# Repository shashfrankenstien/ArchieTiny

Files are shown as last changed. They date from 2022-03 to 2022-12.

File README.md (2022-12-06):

# Archie Tiny OS (ATtiny85)

- https://hackaday.io/project/185844-archie-tiny

<p align="center">
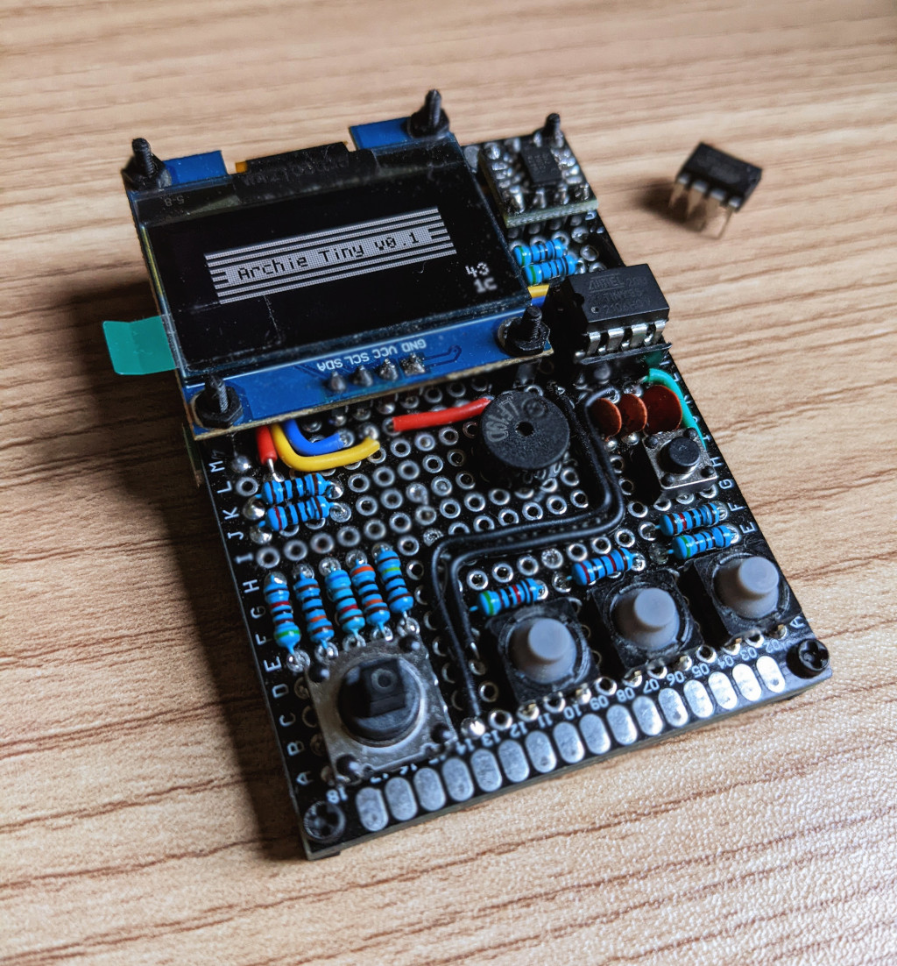
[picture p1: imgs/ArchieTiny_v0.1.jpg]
  
</p>

- https://www.youtube.com/playlist?list=PLuCmHWky5GN4iyRNNchJ4GMcVCSOgdOvc
- http://www.avr-asm-tutorial.net/
- https://blog.oddbit.com/post/2019-01-22-debugging-attiny-code-pt-1/
- http://www.rjhcoding.com/avr-asm-macros.php
- https://www.youtube.com/watch?v=tFSTG7XEboI&list=PLuCmHWky5GN4iyRNNchJ4GMcVCSOgdOvc&index=5
- https://ftp.gnu.org/pub/old-gnu/Manuals/gas-2.9.1/html_chapter/as_7.html

### Portability (CR2477 at 1000 mAh??)
- https://www.batteriesandbutter.com/coin_batttery_chart.html
- http://howardtechnical.com/voltage-divider-calculator/

## Debugging
- https://github.com/vince-br-549/ESP8266-as-ISP
- https://randomnerdtutorials.com/arduino-poor-mans-oscilloscope/
- https://sites.google.com/site/wayneholder/debugwire2
- https://sites.google.com/site/wayneholder/attiny-fuse-reset
- https://sites.google.com/site/wayneholder/attiny-fuse-reset-with-12-volt-charge-pump

## Deps

```
sudo apt-get install avr-libc binutils-avr gcc-avr avrdude
sudo apt install simavr
```

## Simulator

- use simavr + gdb combo - see Makefile sim: and gdb: labels
- simavr clock seems difficult to manage (need to verify) - https://github.com/buserror/simavr/issues/201
- see debug.gdb for hacky time estimation command

to compile simavr, we need glut
```
sudo apt install freeglut3-dev
```

# Digispark
### fuses
- Low fuse: 0xe1  -- 16 MHz mode with no clock divide
- High fuse: 0x5d -- EEPROM not preserved, brown-out detection enabled at 2.7v
- Extended fuse: 0xfe -- Self-programming enabled

# Raw attiny85 using ATTinyDebugTools

https://github.com/shashfrankenstien/ATTinyDebugTools

Function| ATTinyDebugTools | ATtiny85
---|---|---
SCK | D13 | pin 7
MISO | D12 | pin 6
MOSI | D11 | pin 5
VCC | D10 | pin 8
RESET | D6 | pin 1
GND | GND | pin 4

### default fuses
- Low fuse: 0x62  -- 8 MHz mode with clock divide by 8 (1 MHz)
- High fuse: 0xdf -- SPI enabled, EEPROM not preserved
- Extended fuse: 0xff  -- Self-programming disabled

### change to 16 MHz clock
- Low fuse: 0xe1  -- 16 MHz mode with no clock divide

### change to preserve eeprom + brownout detection
- High fuse: 0xd7  -- EEPROM preserved
- High fuse: 0xd6  -- EEPROM preserved + brown out detection at 1.8 volts

# Power Management
- disable Timer1 since we are not using that for anything at the moment (PRR bit 3)
- disable brown-out detection through software while deep sleep
- MCUCR – MCU Control Register - Bit 5 – SE: Sleep Enable
    - The SE bit must be written to logic one to make the MCU enter the sleep mode when the SLEEP instruction is executed
-----

# ArchieTiny implementation NOTES

- Timer 0 in CTC mode - TCNT0,TCCR0A,TCCR0B,OCR0A
- Timer compare A interrupt at addr 0x000A; enabled in TIMSK
- Ugh, need to add `-nostartfiles` to avr-gcc so it doesn't include weird extra code that kills interrupts.
    - This also eliminates need to create and expose a global `main` routine

## Time and Delays (lib/timer.asm)
- Features
    - 24 bit software time counter - this requires that `timer_tick_isr` is attached to an interrupt that triggers every 1 millisecond
    - also includes a sort of accurate clock cycle counter delay. (see `timer_delay_clock_cycles` subroutine)
- Ticks are stored in RAM addressed by TIME_SOFT_COUNTER config variable
    - HIGH_BYTE:MIDDLE_BYTE:LOW_BYTE
    - TIME_SOFT_COUNTER+2:TIME_SOFT_COUNTER+1:TIME_SOFT_COUNTER

## Resource Status Registers
- Each of the below resources are allocated 1 register of size 1 byte to store custom status flags
- Each of these status registers are described within their corresponding modules

Resource | Register config name | Module
---------|----------------------|-------------
Oled     | SREG_OLED            | sh1106.asm
GPIO     | SREG_GPIO_PC         | gpio.asm
I2C      | I2C_BUS_RLOCK        | usi_i2c.asm

## Task Manager (lib/tasks.asm)
Tasks Table is set up starting at RAM address TASK_RAM_START (Should be greater than 0x60 = 32 general registers + 64 I/O registers).

### Task table
- First byte will be the task counter (TASKCTS)
- Second byte will be current task index (TASKPTR)
- Next addresses will contain word size values of task stack pointers

```
         _________
        |_________| --> TASKCTS - task counter and status register (1)
        |_________| --> TASKPTR - current task index / pointer (1)
        |_________| --> task stack pointers vector (TASK_MAX_TASKS*2)
        |         | --> task stack 1 (TASK_STACK_SIZE)
        |_________|
        |         | --> task stack 2 (TASK_STACK_SIZE)
             .
             .
```

### Task workflow
- init
    - set TASKCTS and TASKPTR to 0
- add new task
    - increment TASKPTR till we find an empty slot in TASK_SP_VECTOR
    - calculate stack pointer address and store in TASK_SP_VECTOR at TASKPTR index
    - jump to task's alotted stack
    - store return address, function pointer + manager pushed registers on the stack
        - Note: Because of how the stack works, function pointer address should be divided by 2. cpu will then multiply it by 2 before executing (or we can use pm() apparently)
    - if TASK_SP_VECTOR is full, set FULL flag in TASKCTS
- exec task
    - read TASKCTS counter, if eq 0 or 1, simply return because there is no task switching required
    - if RUNNING bit is set, there was previously a task that was running
    - push registers + SREG to stack, read TASKPTR, save stack pointer in TASK_SP_VECTOR at TASKPTR index
    - increment TASKPTR to go to next task
        - initially, TASKPTR will be 0
        - if TASKPTR overflows beyond TASK_MAX_TASKS, wrap around to 0
    - load stack pointer value from TASK_SP_VECTOR at TASKPTR index
    - set new stack pointer, pop all registers + SREG
    - reti

## I2C (drivers/usi_i2c.asm)
- Built-in USI I2C
    - outputs USIDR MSB on SDA line on falling edge of SCL
    - slave devices read on rising edge of SCL
    - slave addresses seem to be shifted left
        - for example, in SH1106, documentation says addresses are 0111100 and 0111101, but in reality, device only reponds to 01111000 and 01111001
- I2C can only be used by one task at a time. Before using I2C, a task has to acquire a lock

- I2C_BUS_RLOCK - i2c reentrant lock register (1)
```
   -------------------------------------------------------------------------------------
   | RLKCNT3 | RLKCNT2 | RLKCNT1 | RLKCNT0 | TASKPTR3 | TASKPTR2 | TASKPTR1 | TASKPTR0 |
   -------------------------------------------------------------------------------------
```
  - i2c lock is task specific - meaning, each task can acquire locks multiple times (reentrant)
          they only need to release it as many times to fully release the i2c lock
  - a lock can be acquired only if RLKCNT (I2C_BUS_RLOCK[7:4]) is 0
  - when a lock is acquired, I2C_BUS_RLOCK[3:0] is set to current TASKPTR value, and RLKCNT is incremented
  - when a lock is released, RLKCNT is decremented. When it reaches 0, the lock is fully released
  - tasks using i2c should use i2c_rlock_acquire and i2c_rlock_release
      these routines facilitate wait-aquire-release workflow
- i2c_rlock_acquire will sleep till lock can be acquired
  it returns once it is able to acquire the lock

## OLED display - I2C (drivers/sh1106.asm)
- In SH1106 driver, 128x64 OLED is centered in most cases within the 132x64 ram, that means pixel (2,0) in ram is pixel (0,0) on the display
- SH1106 Command Table is on page 30 of the datasheet
- documentation and resources recommend sleeping for 100 ms before displaying anything on the screen
- fonts - https://github.com/Tecate/bitmap-fonts - see vendor/bdf_fonts for more
    - bitocra7
    - spleen
    - unscii-fantasy
- when including strings in program memory, we need to mind byte alignment.
    use `.balign 2` after each string definition
- SREG_OLED is used to track contrast, color inversion (highlight) and page scroll position
```
    --------------------------------------------------------------------------------------------------------------
    |  CNTRST3  |  CNTRST2  |  CNTRST1  |  CNTRST0  |  OLED_COLOR_INVERT  |  SCRL_PG2  |  SCRL_PG1  |  SCRL_PG0  |
    --------------------------------------------------------------------------------------------------------------
```

## OLED text-mode (lib/textmode.asm)
- this module wraps oled and provides helper routines to print continuous text
- it handles control characters
    - '\n' as newline
    - '\b' as backspace
- also manages page scrolling

## Controls (drivers/gpio.asm)
### Button press event manager (PCINT)
- digital pin change interrupts (active low) - interrupt triggers for both falling and rising edges
    - on falling edge (button press), both GPIO_BTN_x_PRS and GPIO_BTN_x_HLD bits are set in SREG_GPIO_PC
    - Any program handling button press must clear GPIO_BTN_x_PRS bit after handing the press
    - on rising edge interrupt (button release), GPIO_BTN_x_HLD bits are automatically cleared

### Button press (voltage divided ADC)
- ADC ISR writes 8-bit precision byte from ADC_CHAN_x to ADC_CHAN_x_VAL register. We can use this byte to identify button press and release
- We need to check expected voltage levels in ascending order
    - only 1 button can be pressed at a time per channel.
    - check lowest voltage threshold. If ADC reading is lower, set ADC_VD_CHx_BTN_y bit in r16 indicating press
    - continue checking as long as no press is identified

- Reading button presses (Software stabilization)
    - ADC clock speed is clk / 128. for clk = 16 MHz, ADC clock speed will be 125 kHz
    - ADC generally takes about 13 - 15 ADC clocks to perform a conversion.
    - Let's approx to 14 which gives us a conversion frequency of ~9 kHz (i.e. each conversion takes ~110 micro seconds)
    - We're using a 680 pF capacitor against 50 k ohm internal pull-up (RESET pin) for smoothing. So, time to charge up to 63% is (50 * 10^3 * 681 * 10^-12) = 34 micro seconds (TAO).
        We might read a wrong value during this charge / discharge time. We can assume that the capacitor will be reasonably full at 5 * TAO
    - Given the ADC conversion period (110 micro seconds), we should make sure multiple readings are within threshold to confirm a button press
    - To be absolutely safe, we can take a bunch of readings waiting a few ms between them; report a press only if all the readings pass the same threshold

- ADC voltage divider value calculation (internal pull up resistance R1)
    - equations (only care about 8 MSB precision)
        - VOUT = lambda VIN, R1, R2: VIN * R2/(R1+R2)
        - ADC_VAL = lambda VREF, VOUT: int((VOUT * 1024) / VREF) >> 2

    - below are approx measured / fudged values that worked out in tests
    - voltages are usually below these values. just to be sure, we set the
        threshold to be a few counts above these values (see config.inc)

    - channel 0: PIN 2 (Attiny85 ADC 3)
        - VREF = Vcc = 2.85 v
        - VIN = Vpin = 2.8 v
        - R1 = 35 kilo ohm aprox (guess??)

ADC button        | Resistance (R2) | Voltage | ADC threshold (8 MSB precision) | V1 Mapping
------------------|-----------------|---------|--------------------------------|-------------
ADC_VD_CH0_BTN_0  | 20 K            | 1.018 v | 0x5b           | OK
ADC_VD_CH0_BTN_1  | 51 K            | 1.660 v | 0x95           | NAV_UP_BTN
ADC_VD_CH0_BTN_2  | 68 K            | 1.849 v | 0xa6           | NAV_DOWN_BTN
ADC_VD_CH0_BTN_3  | 100 K           | 2.074 v | 0xba           | NAV_LEFT_BTN
ADC_VD_CH0_BTN_4  | 300 K           | 2.507 v | 0xe1           | NAV_RIGHT_BTN

- similarly, chanel 1 - PIN 1 (reset pin - Attiny85 ADC 0)
    - VREF = Vcc = 2.8 v
    - VIN = Vpin = 2.45 v
    - R1 = RESET pin pull-up = 50 kilo ohm aprox (guess??)

- when using the reset pin, input voltage cannot be below ~1.3 v (documentation says 0.9 v :/).
    to remedy this, reset pin resistors are all connected in series (each are 68 K)

ADC button        | Resistance (R2) | Voltage | ADC threshold (8 MSB precision) | V1 Mapping
------------------|-----------------|---------|--------------------------------|-------------
ADC_VD_CH1_BTN_0  | 68 K            | 1.412 v | 0x81            | OPTIONS_BTN
ADC_VD_CH1_BTN_1  | 136 K           | 1.791 v | 0xa3            | EXIT_BTN
ADC_VD_CH1_BTN_2  | 204 K           | 1.968 v | 0xb3            | ENTER_BTN

## Keyboard / Typing (lib/kbd.asm)
- text kbd input is just a single character printed with inverted colors
- provides ability to
    - scrub through all characters (SCRUB_NEXT_BTN & SCRUB_PREV_BTN)
    - select the current character (SCRUB_OK_BTN)
    - remove previous character (SCRUB_BACKSP_BTN)
    - add space character (SCRUB_SPACE_BTN)
    - new line (ENTER_BTN)

## Dynamic heap memory allocation - malloc (lib/mem.asm)
- MALLOCFREECTR (1 byte)
    - this counter tracks the number of free blocks available
    - intially, this is set to MALLOC_MAX_BLOCKS

- malloc table (MALLOC_TABLE_SIZE bytes)

```
    |_________|
    |_________| --> MALLOCFREECTR
    |         | --> malloc table index 0 (MALLOC_TABLE_START)
    |         |     .
    |         |     .
    |         |     .
    |_________|     malloc table index MALLOC_MAX_BLOCKS (MALLOC_TABLE_END - 1)
    |         | --> start of malloc blocks (MALLOC_TABLE_END)
```

- bytes in the malloc table are indexed starting with 0 and counting up to MALLOC_MAX_BLOCKS
- each byte corresponds to a block of memory of the same index
- if the value of the byte is 0xff, the block at the corresponding index is free
- if the value of the byte is 0xfe, it means that one block of data is allocated at the index
- if the value of the byte is any other number, that number is the index of the next block of the allocated memory
    - a chain of blocks terminate when the value is 0xfe
- during allocation of multiple blocks, the final block is allocated first, all the way up to the first block
    - this is just because it works with simpler code. should make no other difference

- mallock blocks (MALLOC_BLOCK_SIZE * MALLOC_MAX_BLOCKS bytes)
    - free RAM is allocated in blocks of MALLOC_BLOCK_SIZE
    - block chaining is handled by the malloc table

    - min(MALLOC_FREE_RAM, 256) is divided into blocks of MALLOC_BLOCK_SIZE bytes
        - capped at 256 so that we can use 8 bit pointers and 8 bit MALLOCFREECTR

- MALLOC_MAX_BLOCKS can't be greater than 250 (never gonna happen on this device, but whatever)
    - MALLOC_MAX_BLOCKS is capped at 250 because the last few address values are used as control bytes in the malloc table (0xff, 0xfe, ..)

## FAT-8 File System (lib/fs.asm)
- https://www.youtube.com/watch?v=HjVktRd35G8

- file system (fat-8) - structure is basically very similar to mem.asm
- uses driver/eeprom.asm (or optionally drivers/mb85rc64.asm) to read and write

- FATFREECTR (1 byte)
    - this counter tracks the number of free clusters available
    - intially, this is set to FS_MAX_CLUSTERS

- file allocation table / FAT (FAT_BYTE_SIZE bytes)

```
    |_________|
    |_________| --> FATFREECTR
    |         | --> FAT index 0 (FAT_START) - 2 byte entries
    |         |     .
    |         |     .
    |         |     .
    |_________|     FAT index FAT_BYTE_SIZE (FAT_END - 1)
    |         | --> start of fs clusters (FAT_END)
```

- this implementation of FAT is set of doubly linked lists. this makes it easier/faster to scroll (thinking i2c in the future)
- a pair of bytes in the FAT are indexed starting with 0 and counting up to FS_MAX_CLUSTERS
- each pair corresponds to a cluster of memory of the same index
- first byte is the index of previous cluster (PREV_IDX), and second byte is the index of next cluster (NEXT_IDX)

```
    -------------------------------------------
    | PREV_IDX(1) | NEXT_IDX(1) | .......
    -------------------------------------------
```
- the cluster at the corresponding index is free if the value of both bytes (PREV_IDX and NEXT_IDX) are 0xff
- if the value of both bytes are 0xfe, it means that one cluster of data is allocated at the index
- if the value of either byte is any other number, that number is the index of the prev/next cluster of the allocated disk space
    - the first cluster in a chain of clusters has PREV_IDX value of 0xfe
    - a chain of clusters terminate when the NEXT_IDX value is 0xfe

#### dirent
- directories make up a tree structure across the file system
- when formatted, the fs will have the first cluster allocated to be the root directory
- the root directory may contain entries to more directories
- directory entry cluster - 10 bytes per entry -> 2 entries per cluster of 20 bytes

```
    --------------------------------------------------
    | SIGNATURE(1) |     NAME(8)     | START_ADDR(1) |
    --------------------------------------------------
```
- description
    - NAME (8 bytes)
    - SIGNATURE (1 byte) -> information about the item (is_directory, read_only flags, external mount info)
    - START_ADDR (1 byte) -> cluster address of the first cluster. use FAT to find additional clusters

- unlike typical FAT file systems, directory clusters do not have a '.' or '..' entry (to save space)
    - the caller should instead save parent directory pointers before opening a file or subdirectory

#### fs pointers
- to avoid 16 bit math, fs subroutines work on a pair of values
- when reading raw data (file / directory names or file contents):
    - r16 points to cluster index (possible values: 0 to FS_MAX_CLUSTERS - 1)
    - r17 points to byte index within cluster (possible values: 0 to FS_CLUSTER_SIZE - 1)

- for directory related operations:
    - r16 will contain index to starting cluster
    - r17 will be used to index an item within a directory (may span across clusters. max is 256 items in a dir??)
        - also, r17 index needs to skip over deleted items??? Ugh

- signature byte

```
    --------------------------------------------------------------------------------------------------
    |  IS_EXT_MOUNT  |  N/A  |  N/A  |  N/A  |  N/A  |  FS_IS_DIR  |  FS_IS_DELETED  |  FS_IS_ENTRY  |
    --------------------------------------------------------------------------------------------------
```

#### FRAM fs - I2C

- fs_wrapper_* methods are wrappers around eeprom_* or fram_* routines
- we use these accross the board, and have the ability to switch between internal eeprom and external fram

## File Manager app (based on fs)
- `notes TODO`

## Buzzer - PWM (drivers/buzzer.asm)
- only PB1 (pysical pin 6) is currently supported for buzzer as it uses Timer/Counter1 in PWM1A mode
- PWM_CTRL -> PWM1A enabled; PB1 cleared on compare match and set when TCNT1=0; prescaler at CK/256
    prescaled clock frequency is determined by bits [3:0] of PWM_CTRL byte

- per PWM_CTRL, while running Timer1 in PWM1A mode:
    - a match on compare register A (OCR1A) triggers the PWM signal to go LOW
    - a match on compare register C (OCR1C) triggers the PWM signal to go back HIGH

- PWM_COMPVAL_C controls the frequency / pitch
    - with a 16MHz clock (CK), PWM counter frequency is set to CK/256 in PWM_CTRL
    - PWM_COMPVAL_C acts as the PWM signal divider. so final frequency at the BUZZER_PIN (OC1A) will be CK/256/PWM_COMPVAL_C
    - middle-C musical note (262 Hz) can thus be obtained by setting PWM_COMPVAL_C = 238
        - 16000000 / 256 / 238 = 262.605
        - or more generally, PWM_COMPVAL_C = lambda NOTE_FREQ: int(16000000 / 256 / NOTE_FREQ)
        - ( value floored so as to make the notes slightly sharp )

- PWM_COMPVAL_A controls volume
    - PWM signal at BUZZER_PIN will be HIGH till counter reaches PWM_COMPVAL_A, then goes low till PWM_COMPVAL_C
    - if signal stays HIGH for just as long as it stays LOW, volume is maximum (PWM_COMPVAL_A = PWM_COMPVAL_C / 2)
    - PWM_COMPVAL_A can be varied between 0 and PWM_COMPVAL_C/2 to change volume

- buzzer_macro_play_melody and buzzer melody format
    - buzzer_macro_play_melody takes 2 arguments
        - tempo in milliseconds (1 unit of duration to play a note)
        - melody a sequence of pairs => a note, and duration units to play the note

    - example usage
        - buzzer_macro_play_melody 250 C4 1 D4 1 E4 2 D4 1 C4 1

## Real Time Clock - I2C (based on fs)
- `notes TODO`

## The Shell!
- shell_home_task is the entry point to user space. It is started through task manager
    - starts with a splash screen
    - on button press, shows main menu of applications
- reusable ui components (lib/ui.asm)
    - splash screen (shell.asm)
    - confirm y/n popup
    - scrollable menu

## EEPROM settings (file?) (TODO)

## Text Editor! (TODO)

## Simple Calculator (TODO)

## Game (pong?) (TODO)

-----

[docs/Atmel-AT1886-Mix-C-and-Asm.pdf](docs/Atmel-AT1886-Mix-C-and-Asm.pdf)

Table 5-1. Summary of the register interfaces between C and assembly.
Register | Description | Assembly code called from C | Assembly code that calls C code
---------|-------------|-----------------------------|--------------------------------
r0 | Temporary | Save and restore if using | Save and restore if using
r1 | Always zero | Must clear before returning | Must clear before calling
r2-r17 | “call-saved” | Save and restore if using | Can freely use
r28    | “call-saved” | Save and restore if using | Can freely use
r29    | “call-saved” | Save and restore if using | Can freely use
r18-r27 | “call-used” | Can freely use | Save and restore if using
r30     | “call-used” | Can freely use | Save and restore if using
r31     | “call-used” | Can freely use | Save and restore if using

-----

# Related (and unrelated?)

## Some STM8S stuff

- https://lujji.github.io/blog/

## Some PIC stuff

- https://www.youtube.com/watch?v=DBftApUQ8QI

## Some NRF53832 stuff (PineTime)

- https://infocenter.nordicsemi.com/pdf/nRF52832_PS_v1.8.pdf

-----

# Similar projects

- https://hackaday.com/2019/12/25/circuit-sculpture-teaches-binary-plays-pong/

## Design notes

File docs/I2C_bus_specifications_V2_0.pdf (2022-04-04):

# I2C bus specifications

for the CMS tracker 2S & PS modules

V 2.0

21/4/2016

# Revision History

Version | Date | Comments
V1.0 | 22/11/2015 First draft
V2.0 | 21/4/2016 Device ID extended to 3 bytes. Table 2 revised to reflect the
| | non-programmable CiC address field. Added electrical and timing specifications.

## 1 INTRODUCTION

The present document discusses the implementation of the I²
C serial
communication bus in the CMS Outer Tracker PS (Pixel-Stip) & 2S (Strip-Strip) modules. The use of the I

2
C bus is to monitor and control the operation of the front-end ASICs populating the PS & 2S modules. The aim of the document is to present guidelines for the development of I²
C circuitry of the front-end ASICs.
It should be noted that only a subset of features of the I

2
C Bus standard
are necessary to support the functionality of the ASICs of the PS & 2S modules and therefore the design guidelines are limited to these features. Particular attention is taken not to violate the I²
C Bus standard for the supported features.

The I²
C features for the PS & 2S modules include:
q Compliance to the Philips Semiconductor I² C specification v2.1
q Single master bus
q 7-bit addressing
q Single-byte & Multi-byte transfers
n Need to define maximum number of bytes
q General Call Addressing
n Use within a chip family (CBC, MPA, SSA, CiC)
n Set operational modes, test pulse amplitude & delay, latency value in common for all chips
n CBC2 “broadcast address scheme” (1111111+data+data+….) does not conform to the “General Call Addressing” format but can be generated using standard multi-byte Write transfers (see next slide)
q 100KHz, 400KHz & 1MHz bit rate

### 1.1 I

2
C Bus Topology
The I

2
C Bus Topology for the PS and 2S is shown in Figure 1. The optical link communication ASIC; namely the lpGBT (low power GigaBit Transceiver) is equipped with two independent I²
C master interfaces that realize two independent I2C busses. The lpGBT I²
C master interface is the only master interface permitted to connect on the bus. All front-end ASICs; namely the MPA, the SSA, the CiC, the CBC, must implement an I²

C Slave interface. Generation of clock signals on the I²
C-bus is always
the responsibility of the master device.

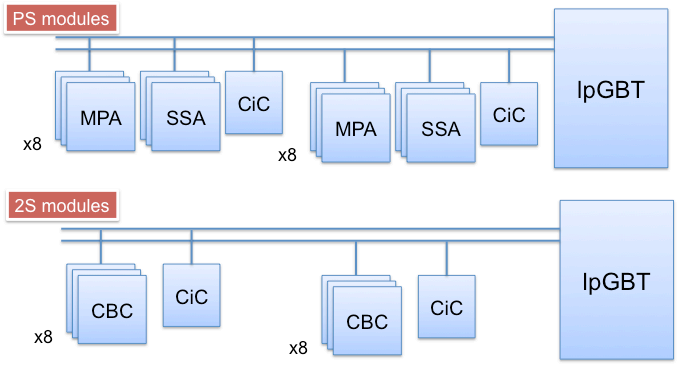
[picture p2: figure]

Figure 1 I2C Bus topology for PS and 2S modules.

### 1.2 SDA & SCL Signals

Both SDA and SCL are bidirectional lines, connected to a positive supply voltage via a current-source or pull-up resistor. When the bus is free, both lines are HIGH. The output stages of devices connected to the bus must have an open-drain to perform the wired-AND function. Data on the I2C-bus can be transferred at rates of up to 100 kbit/s in the Standard-mode, up to 400 kbit/s in the Fast-mode, up to 1 Mbit/s in Fast-mode Plus. The bus capacitance limits the number of interfaces connected to the bus. For a single master application, the master’s SCL output can be a push-pull driver design or an open-drain driver design with an external pull-up resistor. There are no slave devices on the bus which would stretch the clock.

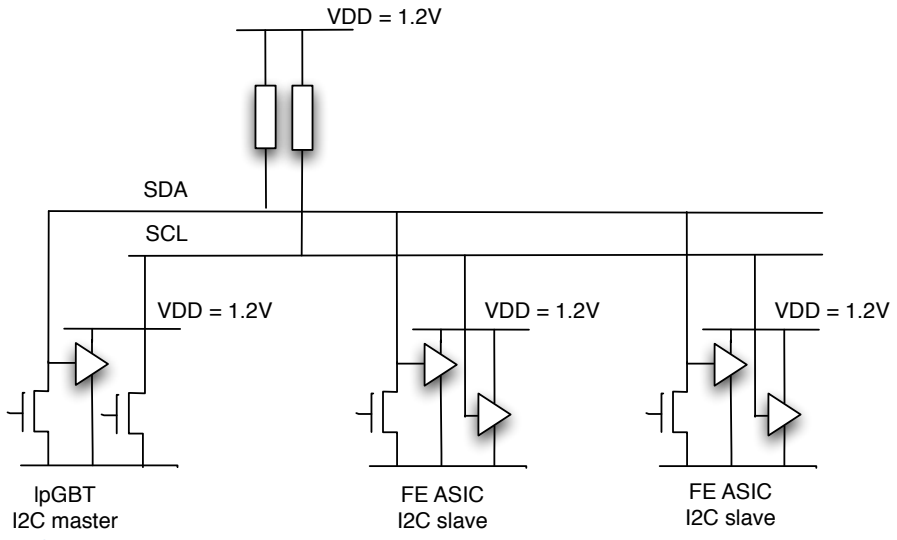
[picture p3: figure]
SDA; SCL; VDD = 1.2V; lpGBT I2C master; FE ASIC I2C slave

Figure 2 I2C bus connectivity

### 1.3 Bus clear

In the unlikely event where the clock (SCL) is stuck LOW, the preferential procedure is to reset the bus using the HW reset signal if the I

2
C devices have HW reset inputs. If the I²
C devices do not have HW reset inputs, cycle power to the devices to activate the mandatory internal Power-On Reset (POR) circuit.
If the data line (SDA) is stuck LOW, the master should send nine clock pulses. The device that held the bus LOW should release it sometime within those nine clocks. If not, then use the HW reset or cycle power to clear the bus. The master I²
C must be
able to generate this “bus clear” sequence.

## 2 DATA TRANSFER PROTOCOL

The data transfer protocol is according to the I

2
C standard. The START, REPEATED START and STOP conditions as well as data transfer protocol are specified in the I2C Specification [PHIL01].
Data transfers follow the format shown in Figure 3. After the START condition (S), a slave address is sent. This address is seven bits long followed by an eighth bit which is a data direction bit (R/W) — a ‘zero’ indicates a transmission (WRITE), a ‘one’ indicates a request for data (READ). A data transfer is always terminated by a STOP condition (P) generated by the master. However, if a master still wishes to communicate on the bus, it can generate a repeated START condition (Sr) and address another slave without first generating a STOP condition.
- Note 1: Each byte is followed by an acknowledgment bit as indicated by the A or A blocks in the sequence.
- Note 2: I2C-bus compatible devices must reset their bus logic on receipt of a START or repeated START condition such that they all anticipate the sending of a slave address, even if these START conditions are not positioned according to the proper format.
- Note 3: 10-bit addressing is NOT supported

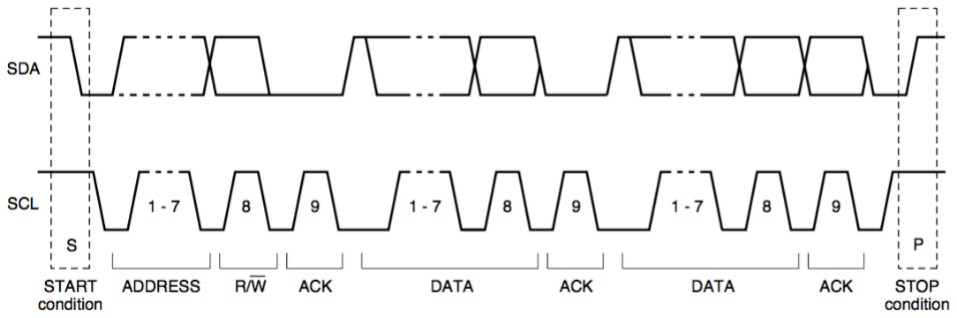
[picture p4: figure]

Figure 3 A complete data transfer
Various combinations of read/write formats are then possible within such a transfer.

### 2.1 Single Read from Random Location

In single read from random location the master does a dummy write operation to desired index, issues a repeated start condition and then addresses the slave again with read operation. After acknowledging its slave address, the slave starts to output data onto SDA line. This is illustrated in Figure 4 . The master terminates the read operation by setting a negative acknowledge and stop condition.

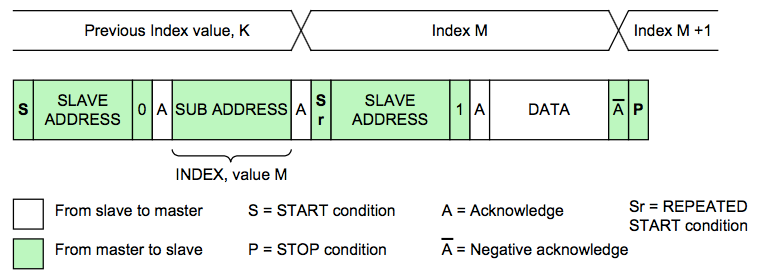
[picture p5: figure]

Figure 4. Single Read from a random location

### 2.2 Sequential Read starting from a Random location

The sequential read starting from a random location is illustrated in Figure 5. The master does a dummy write to the desired index, issues a repeated start condition after an acknowledge from the slave and then addresses the slave again with a read operation. If a master issues an acknowledge after received data it acts as a signal to the slave that the read operation continues from the next index. When the master has read the last data byte it issues a negative acknowledge and stop condition.

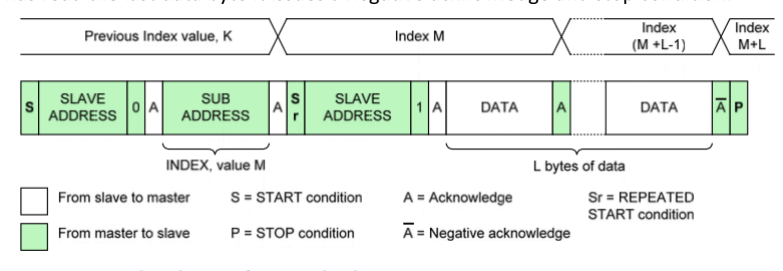
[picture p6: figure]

Figure 5. Sequential Read starting from a random location.

### 2.3 Single Write to a Random location

A write operation to a random location is illustrated in Figure 6. The master issues a write operation to the slave then issues the index and data after the slave has acknowledged the write operation. The write operation is terminated with a stop condition from the master.

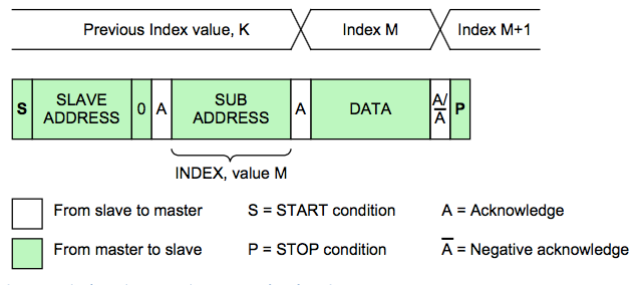
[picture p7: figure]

Figure 6. Single Write operation to a random location.

### 2.4 Sequential Write starting from a Random location

The sequential write operation is illustrated in Figure 7. The slave auto-increments the index after each data byte is received. The sequential write operation is terminated with a stop condition from the master.

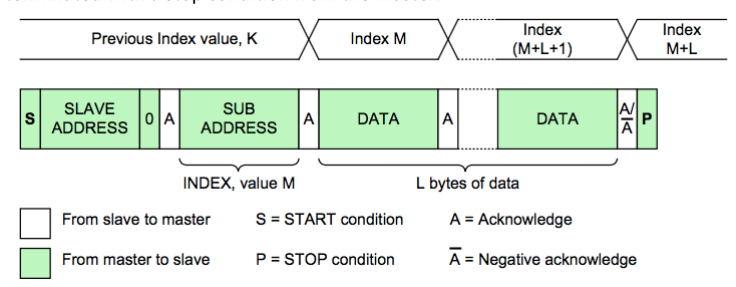
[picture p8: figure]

Figure 7. Sequential Write starting from a random location.

# 3 I

2

## C ADDRESS SPACE

### 3.1 Device addressing

The addressing procedure for the I2C-bus is such that the first byte after the START condition usually determines which slave will be selected by the master. The exception is the ‘general call’ address which can address all devices.
The slave devices on the 2S & PS modules are required to support only the 7-bit addressing mode. The 10-bit addressing mode is not supported.
A slave address of a device is made out of a fixed and a programmable part. The fixed part is internally hardwired and designates the device type. The programmable part consists of address input pins which are hardwired on the hybrid or PCB and allows for addressing several devices of the same type on the same bus.
By convention, we allocate 2 fixed address bit at the MSB part of the 7-bit address field [A6-A5] to identify the device type, see Table 1.
Slave Address [A6-A5] | Device Type
00 | MPA
01 | SSA
10 | CBC
11 | CIC
Table 1 Device Types
Device types have variable programmable address field in order to meet the system level requirements as depicted in the block diagram of Figure 1.
Table 2 presents the allocation of programmable address field per device type (Preliminary allocation scheme.)
Device Type | Programmable Address field | No of devices on same bus
MPA | [A4-A3]=’xx’, [A2-A0] | 8
SSA | [A4-A3]=’xx’, [A2-A0] | 8
CBC | [A4-A0] | 32
CIC | Not programmable | 1
Table 2 Programmable address field for different device types.

### 3.2 Reserved addresses

The I2C specification has reserved two sets of eight addresses, 1111XXX and 0000XXX. These addresses are used for special purposes. Table 3 has been taken from the I2C Specifications.

Slave Address | R/W Bit | Description
000 0000 | 0 | General call address
000 0000 | 1 | START byte(1)
000 0001 | X | CBUS address(2)
000 0010 | X | Reserved for different bus format (3)
000 0011 | X | Reserved for future purposes

000 01XX | X | Hs-mode master code
111 10XX | X | 10-bit slave addressing
111 11XX | X | Reserved for future purposes
Table 3 I2C reserved addresses
(1) No device is allowed to acknowledge at the reception of the START byte.
(2) The CBUS address has been reserved to enable the inter-mixing of CBUS compatible and I2C-bus compatible devices in the same system. I2C-bus compatible devices are not allowed to respond on reception of this address.
(3) The address reserved for a different bus format is included to enable I2C and other protocols to be mixed. Only I2C-bus compatible devices that can work with such formats and protocols are allowed to respond to this address.

### 3.3 General call address

The general call address comprises of a slave address equal to 0000 000 followed by R/W = 0 and is reserved to implement special operations of devices. The general call address is for addressing every device connected to the I²
C-bus at the same time.
However, if a device does not need any of the data supplied within the general call structure, it can ignore this address by not issuing an acknowledgment. If a device does require data from a general call address, it acknowledges this address and behave as a slave-receiver. The master does not actually know how many devices acknowledged if one or more devices respond. The second and following bytes are acknowledged by every slave-receiver capable of handling this data. A slave who cannot process one of these bytes must ignore it by not-acknowledging. Again, if one or more slaves acknowledge, the not-acknowledge will not be seen by the master. The meaning of the general call address is always specified in the second byte.

Figure 8 General Call Address data transfer

### 3.4 Software reset

Following a General Call, (0000 0000), sending 0000 0110 (06h) as the second byte causes a software reset. This feature is optional and not all devices respond to this command. On receiving this 2-byte sequence, all devices designed to respond to the general call address reset and take in the programmable part of their address.

### 3.5 Device ID

Each device must have hardcoded on silicon a unique 3-byte device identifier. Hardcoded device identifier can be implemented with pre-programed laser fuses or electrically programmable fuses.
The Device ID is read only and should be mapped in two consecutive addressed device internal registers.
The Device ID read operation as specified in the I²
C specification is not supported.

## 4 ELECTRICAL SPECIFICATIONS AND TIMING FOR I/O STAGES

The presented electrical specifications depict the guidelines for the implementation of I²
C busses for the 2S and PS modules. The power supply is 1.2V. Even though the targeted bitrate is 1000 kbit/sec, the document gives timing specifications also for fall-back bitrates of 400 kbit/sec and 100 kbit /sec. It is adviced that all devices used in the 2S and PS systems are compatible for all three bit-rates.

### 4.1 DC Electrical Characteristics

Table 4 presents the DC electrical specifications of the I²
C bus implementation
for the 2S and PS modules.
Symbol | Parameter | Conditions
VDD | Supply Voltage | | 1.2 V
VOL | Maximum Low Output Voltage | Iout = 6 mA | 0.2 V
VOH | Maximum High Output Voltage | Iout = -100 uA | VDD + 0.4V
VIL | Maximum Low Input Voltage | | 0.6 V
VIH | Minimum High Input Voltage | | 1.0 V
IL | Maximum Low Sink Current | VOUT = 0.2V | 6 mA
Table 4 DC electrical characteristics

### 4.2 AC Electrical Characteristics

The minimum HIGH and LOW periods of the SCL clock specified in Table 5 determine the maximum bit transfer rates of 100 kbit/s, 400 kbit/s and 1000 kbit/s while Figure 1 depicts the definition of timing of the I²
C bus.
Symbol | Parameter | 100 KHz | 400 KHz | 1000 KHz
tLOW min | Low period of SCL clock | 4700 ns | 1300 ns | 500 ns
tHIGH min | High period of SCL clock | 4000 ns | 600 ns | 260 ns
tR max | Rise time of SCL & SDA | 1000 ns | 300 ns | 120 ns
tF max | Fall time of SCL & SDA | 300 ns | 300 ns | 120 ns
tSU;DAT | Data Setup time | 250 ns | 100 ns | 50 ns
tHD;DAT | Data Hold time | 5000 ns | 900 ns | 450 ns
Table 5 AC electrical specifications

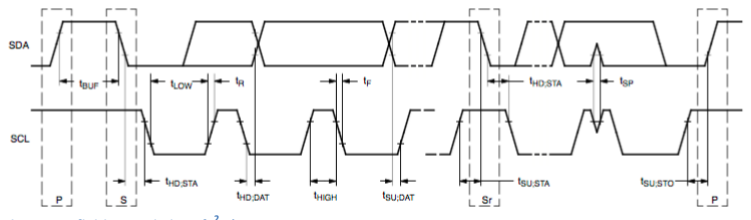
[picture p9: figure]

Figure 9 Definition on timing of I²
C bus

### 4.3 Pull Up resistance calculations

In practical systems the pull-up resistance is determined by the rise time limit for I²
C systems. For example, as an approximation, for a 400 kbit/sec bus, this limit will be satisfied if the time constant (product of the net resistance and net capacitance) of the total system is set to 1 microsecond. The total time constant may either be set by considering the bus node and choosing pull-up resistors to give time constants of 1 microsecond or by combining the capacitances into an equivalent capacitive loading and calculating the bus pull-up resistor required by this equivalent capacitance.
The pull-up resistor may be calculated as follows:
R = 1 μSec Cdevice + Cwiring

Where: Cdevice = sum of device capacitances connected to each bus. and Cwiring = total wiring and stray capacitance on each bus.

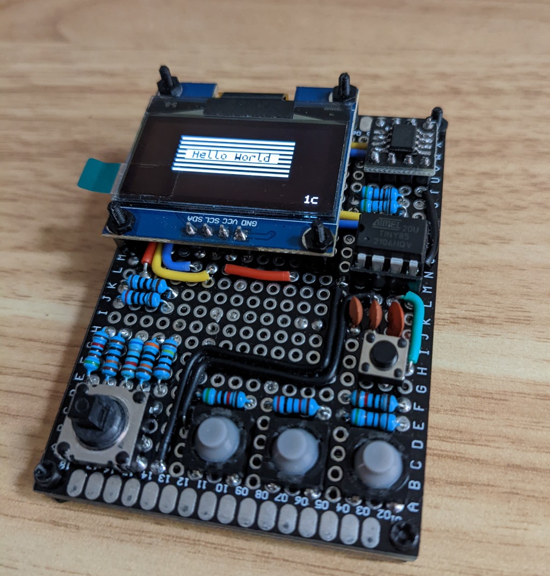
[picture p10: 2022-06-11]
imgs/ArchieTiny_01.jpg

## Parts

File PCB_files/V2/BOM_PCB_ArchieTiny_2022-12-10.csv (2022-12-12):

ID | Name | Designator | Footprint | Quantity | Manufacturer Part | Manufacturer | Supplier | Supplier Part | Price | Pins | 3DModel | Contributor | Frequency | Resistance (Ohms) | link
1 | U-F-M5WD-W-1 | USB-PWR | MICRO-USB-SMD_MICRO-USB-A4 | 1 | U-F-M5WD-W-1 | HRO | LCSC | C145779 | 0.018 | 7 | MICRO-USB-SMD_MICRO-USB-A4 | LCSC |  |  | https://item.szlcsc.com/157111.html
2 | S4B-PH-K(LF)(SN) | I2C | CONN-TH_S4B-PH-K-LF-SN | 1 | S4B-PH-K(LF)(SN) | JST Sales America | LCSC | C265452 | 0.014 | 4 | CONN-TH_S4B-PH-K-LF-SN | LCSC |  |  | https://atta.szlcsc.com/upload/public/pdf/source/20180829/C265452_92616666173A3FAF5DFA68F980034548.pdf
3 | CR2032-BS-6-1 | BT-MAIN | BAT-TH_CR2032-BS-6-1 | 1 | CR2032-BS-6-1 | Q&J | LCSC | C70377 | 0.024 | 2 | BAT-SMD_L28.5-W16.0-H5.5-LS31.3_CR2032-BS-6-1 | 立创EDA官方封装库 |  |  | https://item.szlcsc.com/71472.html
4 | MY-927-01 | BT-RTC | BAT-TH_MY-927-01 | 1 | MY-927-01 | MYOUNG(美阳) | LCSC | C964850 | 0.008 | 3 | BAT-TH_MY-927-01 | LCSC |  |  | https://atta.szlcsc.com/upload/public/pdf/source/20201218/C964850_48FDFDE1A9A12212C9EC07C1F9ECA79B.pdf
5 | 1N5819WS | D1 | SOD-323_L1.8-W1.3-LS2.5-RD | 1 | 1N5819WS | Hottech(合科泰) | LCSC | C191023 | 0.003 | 2 | SOD-323_L1.7-W1.3-H1.1-LS2.5 | LCSC |  |  | https://item.szlcsc.com/295156.html
6 | 47uF | C6 | C0805 | 1 | CL21A476MQYNNNE | SAMSUNG(三星) | LCSC | C16780 | 0.003 | 2 | C0805_L2.0-W1.3-H1.3 | lcsc |  |  | https://item.szlcsc.com/373011.html
7 | 7*7*5-6P-L WX-FIXED | SW-NAV | SW-SMD_6P-L7.0-W7.0-P1.40-LS7.4-FIXED | 1 | 7*7*5-6P-L WX | SHOU HAN(首韩) | LCSC | C2858287 | 0.048 | 6 | SW-SMD_6P-L7.0-W7.0-P1.40-LS7.4 | LCSC |  |  | https://atta.szlcsc.com/upload/public/pdf/source/20210806/C2858287_7956E179246BF43E1C1955FBC790E2E6.pdf
8 | FS9042-03 | BUZZER | BUZ-TH_BD9.0-P4.00-D0.6-FD | 1 | FS9042-03 | FUET(福声科技) | LCSC | C482347 | 0.035 | 2 | BUZ-TH_D9.0-H5.5-P4.0 | LCSC | 2700Hz |  | https://item.szlcsc.com/173200.html
9 | XTL | XTL | OSC-SMD_2P-L1.6-W1.0 | 1 | TFX-04-32.768K | RIVER(大河) | LCSC | C515346 | 0.057 | 2 | OSC-SMD_2P-L1.6-W1.0-H0.5 | LCSC |  |  | https://item.szlcsc.com/176446.html
10 | SSH1106_1.3IN_128X64_I2C_OLED_NEW_TAYEB COPY | DISP | SSH1106 1.3IN 128X64 I2C (HOLES) | 1 | Tribium |  |  |  |  | 4 |  | TayebL
11 | DS1307ZN+ | RTC | SOP-8_L4.9-W3.9-P1.27-LS6.0-BL | 1 | DS1307ZN+T&R | MAXIM(美信) | LCSC | C26858 | 0.151 | 8 | SOP-8_L4.9-W3.9-H1.45-LS6.0-P1.27 | lcsc |  |  | https://item.szlcsc.com/383602.html
12 | SL7333-3 | REG | SOT-23-3_L2.9-W1.6-P1.90-LS2.8-BL-A | 1 | SL7333-3 | Slkor(萨科微) | LCSC | C2826486 | 0.016 | 3 | SOT-23-3_L2.9-W1.6-P1.90-LS2.8-BL-A | LCSC |  |  | https://img.jlc.com//pdf/applyPasteComponent/2021-08-31/265626Z/4af96afe421a4d6381627a0bbc7efa89/HX6286.pdf
13 | 5.1kΩ | R1,R2 | R0402 | 2 | 0402WGF5101TCE | UniOhm | LCSC | C25905 |  | 2 | R0402_L1.0-W0.5-H0.5 | lcsc |  | 5.1K | https://item.szlcsc.com/323315.html
14 | 10uF | C4,C5 | C0402 | 2 | CL05A106MQ5NUNC | SAMSUNG(三星) | LCSC | C15525 | 0.001 | 2 | C0402_L1.0-W0.5-H0.5 | lcsc |  |  | https://item.szlcsc.com/15869.html
15 | Z-10008320100100 | ATTINY85 | DIP-8_L10.2-W10.1-P2.54-LS7.6-BL-1 | 1 | Z-100083200100100 | Nextron(正凌) | LCSC | C115171 | 0.027 | 8 | DIP-8_L10.2-W10.1-P2.54-LS7.6-BL-1 | 官方封装库 |  |  | https://atta.szlcsc.com/upload/public/pdf/source/20210723/C2846064_DCB8E3E6AA95E5E4DE18403700BEA905.pdf
16 | MB85RC64V | FRAM | SOIC-8_L5.0-W4.0-P1.27-LS6.0-BL | 1 | MB85RC64V | FUJITSU | LCSC | C8740 | 0.254 | 8 | SOIC-8_L4.9-W3.9-H1.7-LS6.0-P1.27 | lcsc |  |  | https://item.szlcsc.com/417287.html
17 | TS-KG89U-AT25F | SW-EXIT,SW-OK,SW-OPT | SW-SMD_4P-L4.2-W3.3-P2.15-LS4.7 | 3 | TS-KG89U-AT25F | HANBO(汉博) | LCSC | C2874600 | 0.006 | 4 | SW-SMD_4P-L4.2-W3.3-P2.15-LS4.7 | LCSC |  |  | https://atta.szlcsc.com/upload/public/pdf/source/20190426/C354949_AF33B0EC69C15332C6829760E70F950D.pdf
18 | TS-KG77S-AT20F | SW-PC | KEY-SMD_4P-L3.1-W3.1-P2.00-LS4.0 | 1 | TS-KG77S-AT20F | HANBO(汉博) | LCSC | C2874417 | 0.006 | 6 | KEY-SMD_4P-L3.1-W3.1-P2.00-LS4.0 | LCSC |  |  | https://atta.szlcsc.com/upload/public/pdf/source/20200810/C720461_63203F0B5BA37BBA1A8923CED5CABDCF.pdf
19 | 300kΩ | R6 | R0402 | 1 | 0402WGF3003TCE | UNI-ROYAL(厚声) | LCSC | C25774 |  | 2 | R0402_L1.0-W0.5-H0.5 | lcsc |  | 300K | https://item.szlcsc.com/323315.html
20 | 100kΩ | R4 | R0402 | 1 | 0402WGF1003TCE | UNI-ROYAL(厚声) | LCSC | C25741 |  | 2 | R0402_L1.0-W0.5-H0.5 | lcsc |  | 100K | https://item.szlcsc.com/323315.html
21 | 51kΩ | R5 | R0402 | 1 | 0402WGF5102TCE | UNI-ROYAL(厚声) | LCSC | C25794 |  | 2 | R0402_L1.0-W0.5-H0.5 | lcsc |  | 51K | https://item.szlcsc.com/323315.html
22 | 20kΩ | R7 | R0402 | 1 | 0402WGF2002TCE | UNI-ROYAL(厚声) | LCSC | C25765 |  | 2 | R0402_L1.0-W0.5-H0.5 | lcsc |  | 20K | https://item.szlcsc.com/323315.html
23 | 10kΩ | R11 | R0402 | 1 | 0402WGF1002TCE | UNI-ROYAL(厚声) | LCSC | C25744 |  | 2 | R0402_L1.0-W0.5-H0.5 | lcsc |  | 10K | https://item.szlcsc.com/323315.html
24 | 68kΩ | R3,R8,R9,R10 | R0402 | 4 | 0402WGF6802TCE | UNI-ROYAL(厚声) | LCSC | C36871 |  | 2 | R0402_L1.0-W0.5-H0.5 | lcsc |  | 68K | https://item.szlcsc.com/323315.html
25 | 330pF | C1,C2,C3 | C0402 | 3 | CL05C331JB5NNNC | SAMSUNG | LCSC | C13533 | 0.001 | 2 | C0402_L1.0-W0.5-H0.5 | lcsc |  |  | https://item.szlcsc.com/15869.html
26 | SSAJ120100 | SW-POWER,SW-SELECT | SW-SMD_SSAJ120100 | 2 | SSAJ120100 | ALPSALPINE(阿尔卑斯阿尔派) | LCSC | C160864 | 0.049 | 5 | SW-SMD_SSAJ120100 | LCSC |  |  | https://item.szlcsc.com/172245.html

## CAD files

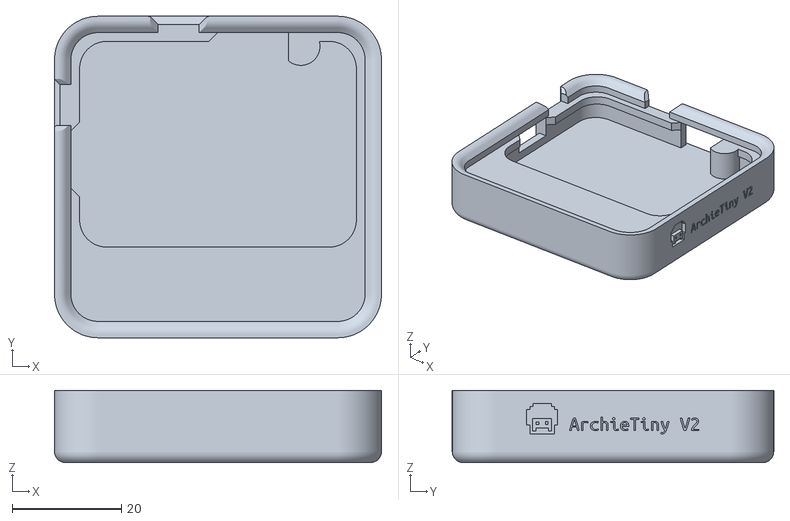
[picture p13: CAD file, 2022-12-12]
PCB_files/V2/ArchieTiny_Case-Case.stl
59.9 x 58.9 x 13.2

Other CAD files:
PCB_files/V2/ArchieTiny_Case.FCStd

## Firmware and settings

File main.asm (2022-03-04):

; General registers / addresses

.equ    SRAM_START,     0x0060
.equ    SRAM_SIZE,      512
.equ    RAMEND,         0x025f

.equ    SPL,            0x3d
.equ    SPH,            0x3e
.equ    SREG,           0x3f


; timer / counter control
; .equ    GTCCR,          0x2C        ; GTCCR – General Timer/Counter Control Register
.equ    TCCR0A,         0x2A        ; TCCR0A – Timer/Counter Control Register A
.equ    TCCR0B,         0x33        ; TCCR0B – Timer/Counter Control Register B
.equ    OCR0A,          0x29        ; OCR0A – Output Compare Register A
.equ    TCNT0,          0x32        ; TCNT0 – Timer/Counter Register
.equ    TIMSK,          0x39        ; TIMSK – Timer/Counter Interrupt Mask Registe
.equ    TIFR,           0x38        ; TIFR – Timer/Counter Interrupt Flag Register

.equ    COUNTER_CTRL_A,    0b00000010   ; mode - 10 = Clear Timer on Compare Match (CTC) mode
.equ    COUNTER_CTRL_B,    0b00000011   ; clk setting (011 = 16 MHz / 64)
.equ    TIMER_INT_MASK,    0b00010000   ; Timer 0 compare match A interrupt

.equ    TIMER_COMPVAL_A,   250          ; timer counts from 0 to TIMER_COMPVAL_A, then resets to 0
                                        ; TIMER_COMPVAL_A value 250 = 1 millisecond
                                        ; this was arrived at using the below equation
                                        ; TIMER_COMPVAL_A = 0.001 * f_cpu / prescale_div
                                        ; if f_cpu = 16 MHz and selected prescale_div = 64, TIMER_COMPVAL_A = 250

; built-in LED control
.equ    DDRB,           0x17
.equ    PORTB,          0x18
.equ    LED_PIN,        1
.equ    SOFT_DELAY,     250             ; custom software scaling limit - with current settings, the unit here is millisecond
                                        ; a value of 250 = 0.25 second

; repurpose r25 for gpio flags
; .req    r25,            r25


; settings to read fuse bits
.equ    SPMCSR,          0x37            ; SPMCSR - Store Program Memory Control and Status Register
.equ    RFLB,            3               ; bit 3 allows reading fuse and lock bits
.equ    SPMEN,           0               ; bit 0 enable program memory control



; MAIN PROGRAM

.org 0                              ; origin - address of next statement
; interrupt vector table
rjmp main                           ; Address 0x0000 - RESET
reti                                ; Address 0x0001 - INT0_ISR
reti                                ; Address 0x0002 - PCINT0_ISR
reti                                ; Address 0x0003 - TIM1_COMPA_ISR
reti                                ; Address 0x0004 - TIM1_OVF_ISR
reti                                ; Address 0x0005 - TIM0_OVF_ISR
reti                                ; Address 0x0006 - EE_RDY_ISR
reti                                ; Address 0x0007 - ANA_COMP_ISR
reti                                ; Address 0x0008 - ADC_ISR
reti                                ; Address 0x0009 - TIM1_COMPB_ISR
rjmp timer0_isr                     ; Address 0x000A - TIM0_COMPA_ISR
reti                                ; Address 0x000B - TIM0_COMPB_ISR
reti                                ; Address 0x000C - WDT_ISR
reti                                ; Address 0x000D - USI_START_ISR
reti                                ; Address 0x000E - USI_OVF_ISR

tasks_jump_table:
    .word blink
    .word test1
    .word test2
    .word 0x0000


timer0_isr:
    inc r20
    .irp param,0,1,2,3,4,30,31
        push r\param
    .endr
    in r4, SREG

    lpm r0, Z+                  ; copy low byte
    lpm r1, Z+                  ; copy high byte
    lpm r2, Z+                  ; copy next low byte to check end of jump table
    lpm r3, Z                   ; copy next low byte to check end of jump table
    mov r30, r0                 ; set ZL
    mov r31, r1                 ; set ZH
    lsr r31                     ; Divide r31:r30 by 2
    ror r30                     ; r31:r30 is an unsigned 2-byte integer
                                ; division by 2 seems important here
                                ; because since icall seems to be multiplying the value by 2 :/
    icall                       ; call the current task subroutine
    pop r31
    pop r30
    clr r0
    cpse r2, r0                 ; here r2 and r3 make the next tasks_jump_table word. check to see if end reached (0x0000)
    rjmp timer0_isr_done1       ;
    cpse r3, r0                 ;
    rjmp timer0_isr_done1       ;
    rcall init_taskmanager      ; reached the end. init task manager to reset to the top of tasks_jump_table
    rjmp timer0_isr_done2
timer0_isr_done1:               ; if we jump here, there are more tasks in the jump table
    adiw r30, 2                 ; increment Z pointer by 2 to the next task (16 bit addressing)
timer0_isr_done2:
    out SREG, r4
    .irp param,4,3,2,1,0
        pop r\param
    .endr
    reti



init_timer:
    ldi r16, COUNTER_CTRL_A
    out TCCR0A, r16                 ; mode select

    ldi r16, COUNTER_CTRL_B
    out TCCR0B, r16                 ; clk select

    ldi r16, TIMER_COMPVAL_A
    out OCR0A, r16

    ldi r16, TIMER_INT_MASK
    out TIMSK, r16                  ; enable interrupt
    ret


init_taskmanager:
    ldi r31, hi8(tasks_jump_table)      ; Initialize Z-pointer with address to tasks_jump_table
    ldi r30, lo8(tasks_jump_table)
    ret


init_onboard_led:
    sbi DDRB, LED_PIN               ; setup output pin 1 (P1)
    out PORTB, 0
    ldi r25, (1<<(LED_PIN-1))                ; use r25 to toggle
    clr r20                         ; software scaling counter to blink LED
    ldi r21, SOFT_DELAY             ; software scaling limit
    ret



main:                               ; initialize
    cli
    ldi r16, lo8(RAMEND)            ; set stack pointer low bits to low(RAMEND)
    out SPL, r16
    ldi r16, hi8(RAMEND)            ; set stack pointer high bits to high(RAMEND)
    out SPH, r16

    rcall init_timer                ; set timer / counter options
    rcall init_onboard_led          ; set LED output pin
    rcall init_taskmanager
    sei

pool:
    sleep                           ; (required for simavr to perform correctly)
    rjmp pool




blink:
    cpi r20, SOFT_DELAY             ; Compare registers
    brsh blink_timeout
    ret
blink_timeout:
    clr r20
    sbrc r25, LED_PIN-1             ; if value is unset, continue to "on", else unset it in the "off" label
    rjmp off
on:
    sbi PORTB, LED_PIN              ; set bit
    sbr r25, (1<<(LED_PIN-1))
    ret
off:
    cbi PORTB, LED_PIN              ; clear bit
    cbr r25, (1<<(LED_PIN-1))
    ret



read_fuse:
    ldi r22, (1<<RFLB) | (1<<SPMEN)
    out SPMCSR, r22
    lpm r22,Z+
    ret

test2:
    push r30
    push r31
    push r22
    clr r31
    clr r30
    rcall read_fuse
fuse_low:           ; break here and see r22 for fuse low byte
    rcall read_fuse
lock_bits:           ; break here and see r22 for lock bits
    rcall read_fuse
fuse_ext:           ; break here and see r22 for fuse ext byte
    rcall read_fuse
fuse_high:           ; break here and see r22 for fuse high byte
    pop r22
    pop r31
    pop r30
    ret


test1:
    .irp param,16,17,18,30,31
    push r\param
    .endr
    in r18, SREG

    ldi r31, hi8(data_table_1)      ; Initialize Z-pointer
    ldi r30, lo8(data_table_1)
    lpm r16, Z+                     ; Load constant from Program
                                    ; Memory pointed to by Z (r31:r30)
    lpm r17, Z
test1_breakpoint:
    out SREG, r18
    .irp param,31,30,18,17,16
    pop r\param
    .endr
    ret


data_table_1:
    .word 0x5276                        ; 0x76 is addresses when ZLSB = 0
                                        ; 0x58 is addresses when ZLSB = 1
    .word 0x9911

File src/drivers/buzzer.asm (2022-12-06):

; piezo buzzer for audio
.include "config.inc"                       ; BUZZER_VOLUME_REG, BUZZER_PIN


.if BUZZER_PIN - 1                          ; only PB1 (pysical pin 6) is currently supported for buzzer
    .error "BUZZER_PIN - unsupported pin!"
.endif


; timer / counter PWM control - Timer1
.equ    TCCR1,              0x30            ; TCCR1 – Timer/Counter1 Control Register

.equ    TCNT1,              0x2f            ; TCNT1 – Timer/Counter1 Register
.equ    OCR1A,              0x2e            ; OCR1A – Timer/Counter1 Output Compare RegisterA
.equ    OCR1C,              0x2d            ; OCR1C – Timer/Counter1 Output Compare RegisterC

.equ    PWM_CTRL,           0b01101001      ; PWM1A enabled; PB1 cleared on compare match and set when TCNT1=0; prescaler at CK/256
                                            ; prescaled clock frequency is determined by bits [3:0] of PWM_CTRL byte

; per PWM_CTRL, while running Timer1 in PWM1A mode:
;   - a match on compare register A (OCR1A) triggers the PWM signal to go LOW
;   - a match on compare register C (OCR1C) triggers the PWM signal to go back HIGH
;
; PWM_COMPVAL_C controls the frequency / pitch
;   - with a 16MHz clock (CK), PWM counter frequency is set to CK/256 in PWM_CTRL
;   - PWM_COMPVAL_C acts as the PWM signal divider. so final frequency at the BUZZER_PIN (OC1A) will be CK/256/PWM_COMPVAL_C
;   - middle-C musical note (262 Hz) can thus be obtained by setting PWM_COMPVAL_C = 238
;       - 16000000 / 256 / 238 = 262.605
;       - or more generally, PWM_COMPVAL_C = lambda NOTE_FREQ: int(16000000 / 256 / NOTE_FREQ)
;       - ( value floored so as to make the notes slightly sharp )
.equ    BUZZ_NOTE_C4,       238             ; C4 (262 Hz)
.equ    BUZZ_NOTE_D4,       212             ; D4 (294 Hz)
.equ    BUZZ_NOTE_E4,       189             ; E4 (330 Hz)
.equ    BUZZ_NOTE_F4,       178             ; F4 (350 Hz)
.equ    BUZZ_NOTE_G4,       159             ; G4 (392 Hz)
.equ    BUZZ_NOTE_A4,       142             ; A4 (440 Hz)
.equ    BUZZ_NOTE_B4,       126             ; B4 (494 Hz)
;
.equ    BUZZ_NOTE_C5,       119             ; C5 (524 Hz)
.equ    BUZZ_NOTE_D5,       106             ; D5 (588 Hz)
.equ    BUZZ_NOTE_E5,       94              ; E5 (660 Hz)
.equ    BUZZ_NOTE_F5,       89              ; F5 (699 Hz)
.equ    BUZZ_NOTE_G5,       79              ; G5 (784 Hz)
.equ    BUZZ_NOTE_A5,       71              ; A5 (880 Hz)
.equ    BUZZ_NOTE_B5,       63              ; B5 (988 Hz)
;
.equ    BUZZ_NOTE_C6,       59              ; C6 (1047 Hz)
.equ    BUZZ_NOTE_D6,       53              ; D6 (1175 Hz)
.equ    BUZZ_NOTE_E6,       47              ; E6 (1319 Hz)
.equ    BUZZ_NOTE_F6,       44              ; F6 (1397 Hz)
.equ    BUZZ_NOTE_G6,       39              ; G6 (1568 Hz)
.equ    BUZZ_NOTE_A6,       35              ; A6 (1760 Hz)
.equ    BUZZ_NOTE_B6,       31              ; B6 (1976 Hz)
;
.equ    BUZZ_NOTE_C7,       29              ; C7 (2093 Hz)
.equ    BUZZ_NOTE_D7,       26              ; D7 (2350 Hz)
.equ    BUZZ_NOTE_E7,       23              ; E7 (2637 Hz)
.equ    BUZZ_NOTE_F7,       22              ; F7 (2794 Hz)
.equ    BUZZ_NOTE_G7,       19              ; G7 (3136 Hz)
.equ    BUZZ_NOTE_A7,       17              ; A7 (3520 Hz)
.equ    BUZZ_NOTE_B7,       15              ; B7 (3951 Hz)
;
.equ    BUZZ_NOTE_C8,       14              ; C8 (4186 Hz)
;
; PWM_COMPVAL_A controls volume
;   - PWM signal at BUZZER_PIN will be HIGH till counter reaches PWM_COMPVAL_A, then goes low till PWM_COMPVAL_C
;   - if signal stays HIGH for just as long as it stays LOW, volume is maximum (PWM_COMPVAL_A = PWM_COMPVAL_C / 2)
;   - PWM_COMPVAL_A can be varied between 0 and PWM_COMPVAL_C/2 to change volume


; BUZZER_VOLUME_REG (1)
;   - buzzer volume register holds current volume level in 4 low bits [3:0] - can be set using buzzer_set_volume routine
;   - it also has a flag to indicate if buzzer is muted (bit 7)
;      -----------------------------------------------------------------------------------------------
;      |  BUZZ_MUTE  |  N/A  |  N/A  |  N/A  |  BUZZ_VOL3  |  BUZZ_VOL2  |  BUZZ_VOL1  |  BUZZ_VOL0  |
;      -----------------------------------------------------------------------------------------------
.equ    BUZZ_MUTE_BIT,      7




buzzer_init:
    ldi r16, 10
    rcall buzzer_set_volume
    ret


; buzzer_set_volume takes volume value in r16
;   - supported values are between 0 and 15
;   - has the effect of unmuting by clearing BUZZ_MUTE_BIT
buzzer_set_volume:
    andi r16, 0b00001111            ; only keep low 4 bits (0 to 15)
    sts BUZZER_VOLUME_REG, r16      ; set BUZZER_VOLUME_REG
    ret


; buzzer_toggle_mute toggles the BUZZ_MUTE_BIT bit in BUZZER_VOLUME_REG
;  - returns non-zero for muted and 0 for unmuted in r16
buzzer_toggle_mute:
    push r17
    lds r16, BUZZER_VOLUME_REG      ; read current volume register

    ldi r17, (1<<BUZZ_MUTE_BIT)     ; toggle mute bit
    eor r16, r17
    sts BUZZER_VOLUME_REG, r16      ; set BUZZER_VOLUME_REG
    pop r17
    andi r16, 0b10000000            ; r16 is returned as non-zero if muted
    ret



; internal_buzzer_set_pwm_compare_A sets compare match A to a proportional value based on volume
; - takes note value (compare match C) in r16
; - takes volume level in r17 - scales volume from (0 to 15) to (1 to r16/2)
;   - this is done by -> (r16 / 2) * (r17 / 15)
internal_buzzer_set_pwm_compare_A:
    push r18

    lsr r16                         ; (r16 / 2)
    rcall mul8                      ; (r16 / 2) * r17

    ; r17:r16 contains a likely 16 bit result. this can be divided by 15 like below
    ;   - (MSB * 256 / 15) + (LSB / 15)
    push r16                    ; save LSB for later
    mov r16, r17                ; get MSB in r16
    ldi r17, (256 / 15)
    rcall mul8                  ; (MSB * 256 / 15)
    mov r18, r16                ; result will be less than 256. save in r18

    pop r16                     ; restore previous LSB
    ldi r17, 15
    rcall div8                  ; (LSB / 15)

    add r16, r18                ; (MSB * 256 / 15) + (LSB / 15) or rather, (r16 / 2) * (r17 / 15)

    cpi r16, 1                  ; minimum allowed value is 1 (this will be used if output value is 0)
    brsh _buzzer_set_pwm_compare_A_ok
    ldi r16, 1
_buzzer_set_pwm_compare_A_ok:
    out OCR1A, r16                  ; load compare A register

    pop r18
    ret
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

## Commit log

2022-02-27 increase timer interrupt speed to 1 ms
2022-03-04 improve timer frequency + implement multitasking. wow.
2022-03-10 task manager: reduce mem used in task frames
2022-03-28 timer bug fix - cli before reading data
    [kernel.asm]
2022-04-04 integrate and test sh1106 oled over hw i2c
2022-04-06 flip oled screen on init + comments
    [kernel.asm, sh1106.asm, usi_i2c.asm]
2022-04-10 add pin change interrupt handler + hardware debouncing
2022-04-11 add ADC for thumb wheel + i2c multitasking locks
2022-04-13 bug fix - multiple tasks using r5 without saving
    [kernel.asm, sh1106.asm]
2022-04-16 implement resource status registers + oled inverted output
    [gpio.asm, kernel.asm, sh1106.asm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]
2022-04-16 implement button press and hold flags in SREG_GPIO
2022-04-16 wired up and tested two buttons
2022-04-16 first pass at typing with 2 buttons :D
2022-04-19 tune voltage divided ADC buttons on RESET pin
2022-04-19 improve ADC button stability + add more text typing actions
    [gpio.asm, kernel.asm, sh1106.asm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]
2022-04-20 further improve ADC button stability with more samples
2022-04-24 move files to lib and drivers sub folders
2022-05-16 bug fix mem.asm - fix add with carry insts
    [shell.asm]
2022-05-18 implement alert popup with Ok button
2022-05-30 utilize ADC channel 2 for more (better) buttons
2022-05-31 improve buttons naming in kbd.asm for easy reconfig
2022-06-02 remove brown-out detection -> fixes constant resets while on battery
    [gpio.asm, kernel.asm, shell.asm]
2022-06-04 include 5 way nav switch documentation
2022-06-11 add mb85rc64 FRAM test code and i2c scanner
2022-06-11 finally finish hand held version on bare pcb
2022-06-21 add preliminary file manager app + ui menu bug fixes
    [shell.asm]
2022-06-22 add ui menu support for other action btns + start buzzer.asm
    [buzzer.asm, gpio.asm, kernel.asm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]
2022-06-25 refactor i2c lock using TASKPTR, remove oled lock
2022-06-26 convert i2c lock into a reentrant lock
2022-11-20 reconfigure ADC pins and resistor configuration - add hardware reset protection
    [kernel.asm]
2022-11-21 improve ADC stability - increase re-reads
    [kernel.asm]
2022-11-21 include PCB v1 gerber, bom and cpl files
    [BOM_PCB_ArchieTiny_2022-11-20.csv, PickAndPlace_PCB_ArchieTiny_2022-11-20.csv]
2022-11-27 implement and test buzzer with 4 octaves of notes
    [buzzer.asm, sh1106.asm, shell.asm]
2022-11-27 move PCB files to V1 folder
    [BOM_PCB_ArchieTiny_2022-11-20.csv, BOM_PCB_ArchieTiny_2022-11-21.csv, PickAndPlace_PCB_ArchieTiny_2022-11-20.csv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]
2022-11-27 add and test ds1307 RTC over i2c driver
2022-11-27 update readme with details of buzzer impl
    [buzzer.asm]
2022-11-28 implement buzzer play melody, volume and mute control
    [buzzer.asm, kernel.asm, sh1106.asm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]
2022-12-12 new V2 PCB ordered - now comes with an all new case (if it all works out)
    [ArchieTiny_Case-Case.stl, ArchieTiny_Case.FCStd, BOM_PCB_ArchieTiny_2022-12-10.csv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]
